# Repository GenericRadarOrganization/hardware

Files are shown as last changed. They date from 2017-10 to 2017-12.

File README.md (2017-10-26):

# hardware
Design Files for Radar Board. Including Kicad Project and Individual Schematics

# Program Requirements
* KiCAD : http://kicad-pcb.org/download/
* GitDesktop (Optional) : https://desktop.github.com/

# How to Operate:
1. Checkout Repositiory
2. Open the "Radar.pro"
3. Find the Schemtatic of which you are responsible for and do your work within that
4. Commit and push your changes, making sure you only changed your schematic
5. Make sure to Pull before you begin edditing

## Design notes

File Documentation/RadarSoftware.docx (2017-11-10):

Software/Signal Processing

This document outlines the basic behavior of the software components of the radar project. The software is responsible for the management of a collection of inputs and outputs: the VCO control waveform, the VCO enable signal, and the mixed-down receive waveform. It uses those inputs and outputs to calculate the range and speed of an object. To accomplish this, the software has been divided into four basic modules: ADC, ADC processing, DAC, and GUI.

The ADC and ADC processing modules are closely interrelated. To ensure a consistent sample rate, the ADC module uses a hardware peripheral of the MKL26Z4 microcontroller on the teensy board called the periodic interrupt timer (PIT) to generate a constant clock signal at the desired sampling frequency. The ADC can then be configured to start a conversion on every rising clock edge of the PIT. This allows consistent conversion with no processor intervention. To close the loop, the direct memory access (DMA) module is configured to automatically transfer data from the ADC to a 512 byte buffer whenever a new reading is available. This allows the firmware to trigger a reading of 512 12-bit words from the ADC at a constant sample rate with only one function call to trigger the required peripherals.

The ADC processing module uses the ADC module’s API to trigger readings and then process the returned data. To determine the frequency of the input waveform, some basic processes are used. First, the module loops over the collected data and determines the average value. Then, the module subtracts that average from every sample. The module then loops over the data to find zero crossings, recording the index of each crossing found. Finally, the difference between each recorded index is averaged together and doubled to calculate the average period (in samples) of the collected waveform. The received frequency can then be determined by dividing the sampling rate by the average period in samples.

The DAC module facilitates control of the transmit stage of the radar. It outputs a constant voltage or a variable voltage waveform to control the output frequency of the VCO. Currently, the DAC is configured to output a set voltage to keep the VCO at a continuous frequency. This is important for use as a doppler radar. The user can configure the voltage output during runtime to change the base frequency of the radar, but sweeps cannot yet be configured. The DAC module is planned to allow the user to select the range and period of the sawtooth wave used to sweep the VCO for FMCW operation.

Finally, the GUI module glues together all the underlying modules and handles all user interaction. It displays a splash screen on an LCD with the company logo upon boot and then switches to the main menu page after a timeout or button press. The user can then use the hardware buttons to enable or disable the radar, vary the frequency of operation, or force the radar to operate in one-shot mode. In one-shot mode, the radar will only capture and process one 512-byte block of data. This would allow the user to point the radar at an object of interest and capture a single speed or distance measurement.

The firmware is maintained on Github: https://github.com/GenericRadarOrganization/firmware. It requires that the user has the arm-none-eabi flavor of GCC installed locally as well as the teensy loader CLI for loading the firmware. To build and flash the firmware, the command “make burn” must be run in the root directory of the project.

ECE 764 Radar Project Thomas Gorham

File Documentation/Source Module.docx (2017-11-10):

Source Module - Damian Loya

The goal of this portion of the Radar is to create and send a clean 5.8 GHz signal to the other modules. This is done by using a voltage controlled oscillator whose output frequency will be set by an Teensy ADC output. The output frequency will be 1.93 GHz which is then multiplied into the desired 5.8 GHz, after being amplified. After the multiplier there is a filter to attenuate any of the 1.93 GHz that leaks through the multiplier. The 5.8 GHz signal is then amplified again before being split in the Wilkinson divider. This module is found on the fourth page of the schematic, based on the initial block diagram given in the project description. I will now explain each of the components in more detail.

Starting off is the voltage controlled oscillator (VCO), the exact model is MAX 2752. This component can take in a voltage from 0V to 3.3V (VCC) which corresponds to its frequency range of 1875 MHz to 2275 MHz. The supporting circuitry is set up according to the application guide found in the datasheet.

The Amplifiers Selected are the GALI -2+ because they were the best performing at 5.8GHz according to the data sheet. The simulated gain of each one had around 12 dB of gain, a more detailed chart which the different power levels is included as well. To power the amplifiers there is a DC line with a AC grounding capacitor at a distance of λ/4 from the output. There are also DC blocking capacitors on both the inputs and outputs.

The frequency multiplier being used is the RMK -3-93+. This is one of the reasons, so much gain is needed from the amplifiers. It needs at least 7dBm of input and has a conversion loss of around 16.5 DB at 5.8GHz. On issues is that it lets through a decent amount of the original frequency. This is an issue because we do not want to unintentionally transmit this frequency. So the output signal is then filtered with a single pole filter to further attenuate the 1.9 GHz signal.

Once Amplified again the signal is sent through a Wilkinson power divider. This ideal should take a signal and split it into two -3dB signals. When simulated in ADS each signal was closer to -3.1dB. Drawing the Shape within KiCad was one factor that lead to a blockier shape rather than a horse shoe or omega shape.

Also included on the Schematic is a resistive divider which could be used to monitor the 1.93 GHz signal form the VCO. Th pads could be left unpopulated and zero-ohm resistors can be used to bypass it. Another thing that was placed on the VCO board was the Voltage regulator which takes in 9V from the battery and regulates it to 5V. The Teensy is powered of this, and also is used to regulate the 5V. into 3.3V.

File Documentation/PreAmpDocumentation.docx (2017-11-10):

Downconverter/Baseband Preamp Module – Katie Dhuyvetter

This portion of the radar converts the high RF signal coming in from the TX/RX module to a low RF signal. It also contains the preamp so that the weak electrical signal can be processed by the DSP module.

The circuit schematic for this module can be seen on page two of the schematic. The initial circuit was based off the simplified block diagram given in the project assignment packet. I began the circuit by looking at the data sheets of the various parts needed. I selected the following parts: LMV751 low-noise op-amps, MCA1-85L+ frequency mixer, GALI-1+ amplifier, resistors, capacitors, and a potentiometer. The resistors and the capacitors were used in conjunction with the amplifiers to get the desired gain. The potentiometer was selected so that the gain of the preamp can be easily altered. The remaining parts will be discussed in more detail below.

The low-noise op-amps were selected to be used as the preamp gain amplifiers. Resistor values were chosen such that the first op amp gives a gain of 1000. The second op-amp uses the potentiometer to have a variable gain value. The DSP module needs 3.3 V of input, so the variable gain amp will allow us to alter the input gain such that it is the correct value.

The GALI-1+ was chosen as the amplifier that connects the source module with the frequency mixer. This is because upon inspection of the data sheet, the frequency mixer was found to need +4 dBm of input and the GALI-1+ was the smallest amplifier provided with a gain of 10 dB. Capacitor values were chosen based on the frequency value of 5.8 GHz to accompany the amplifier. These values were able to be taken from the third lab because the same amp and frequency were used for the lab.

The frequency mixer takes in the local oscillator value from the amplified source module input and the RF input directly from the TX/RX module. The mixer is used to mix the two frequencies, creating a new output frequency. It is the first step of the downconverter system for this module. The next step of the downconverter is the low pass filter. The low pass filter was first created using the LMV751 op amp along with a resistor and a capacitor. The filter was then altered from the op-amp based filter to a single-pole stub filter. The new filter is a simpler way to filter the signal. The stub length was set to a quarter of the wavelength. The calculations used to find the wavelength can be seen below.

v= c/(√(ε_r))

λ= v/f

The εr value used was 4.6 and the frequency used was 5.8 GHz. The final value of the stub length was calculated to be 0.2374 inches.

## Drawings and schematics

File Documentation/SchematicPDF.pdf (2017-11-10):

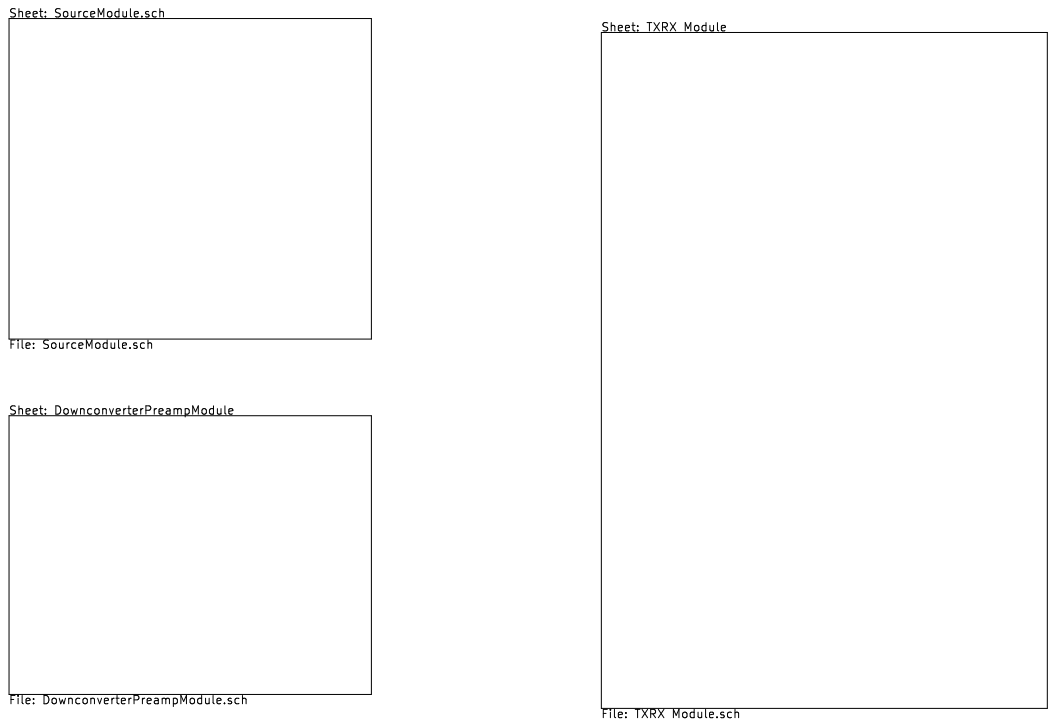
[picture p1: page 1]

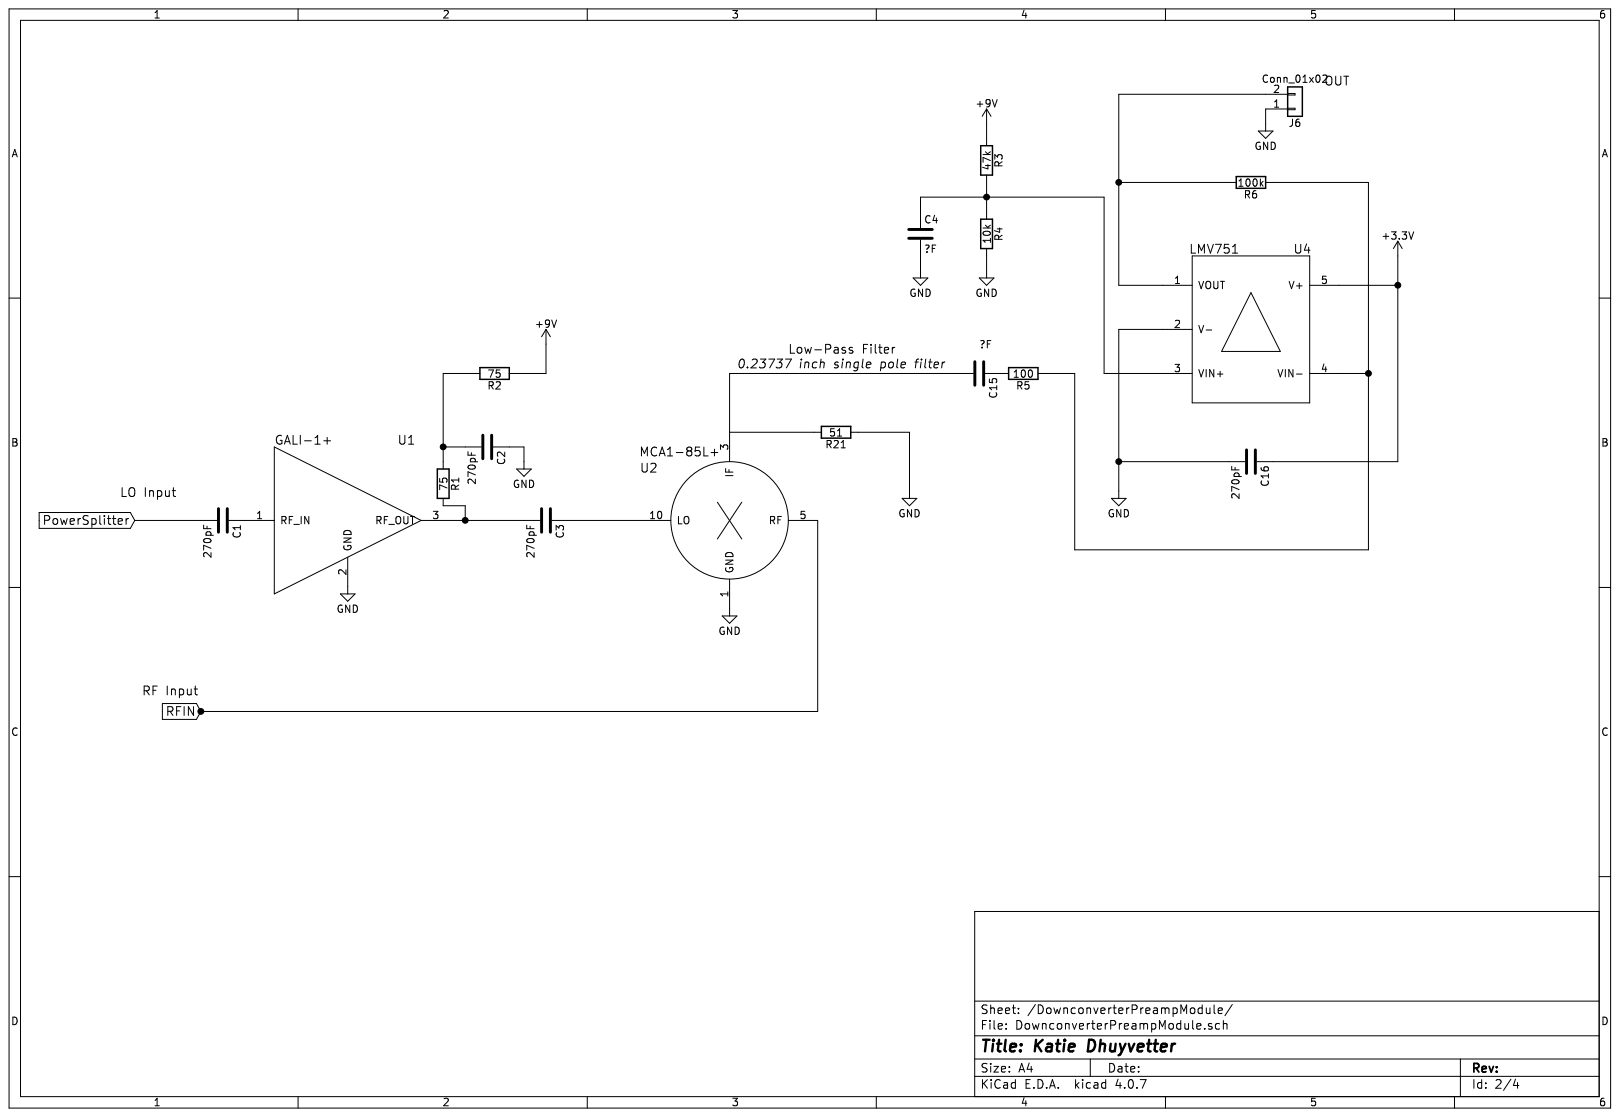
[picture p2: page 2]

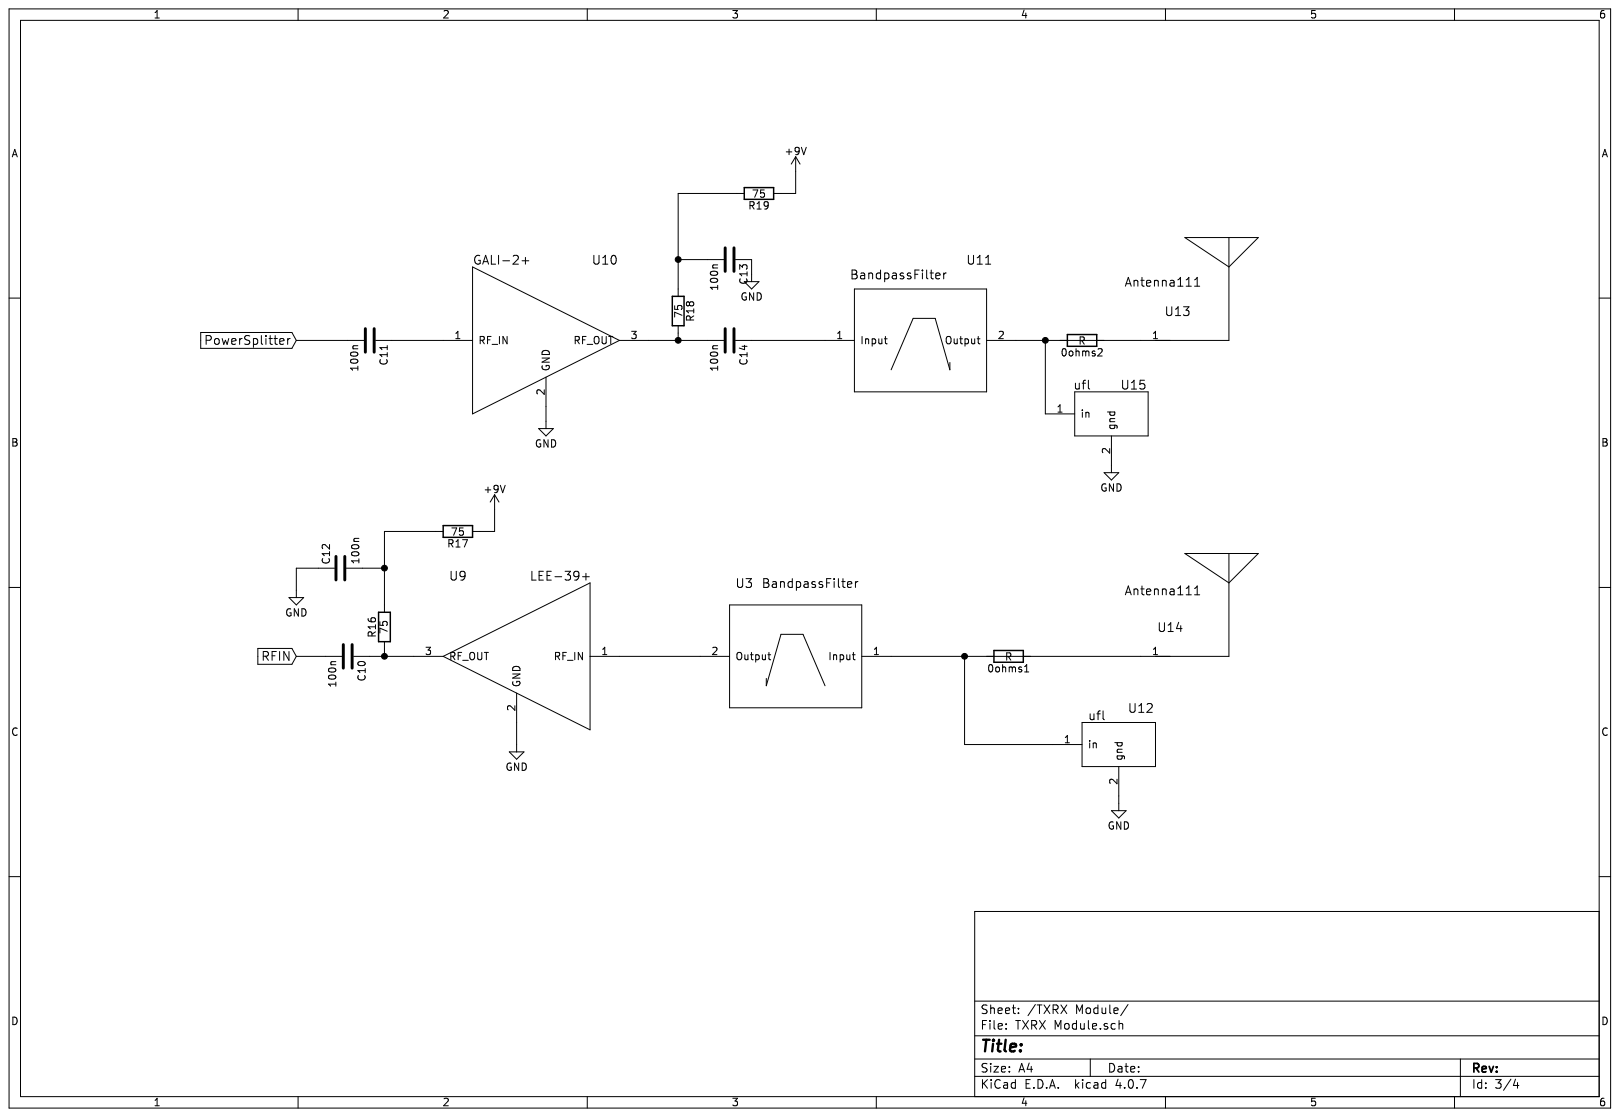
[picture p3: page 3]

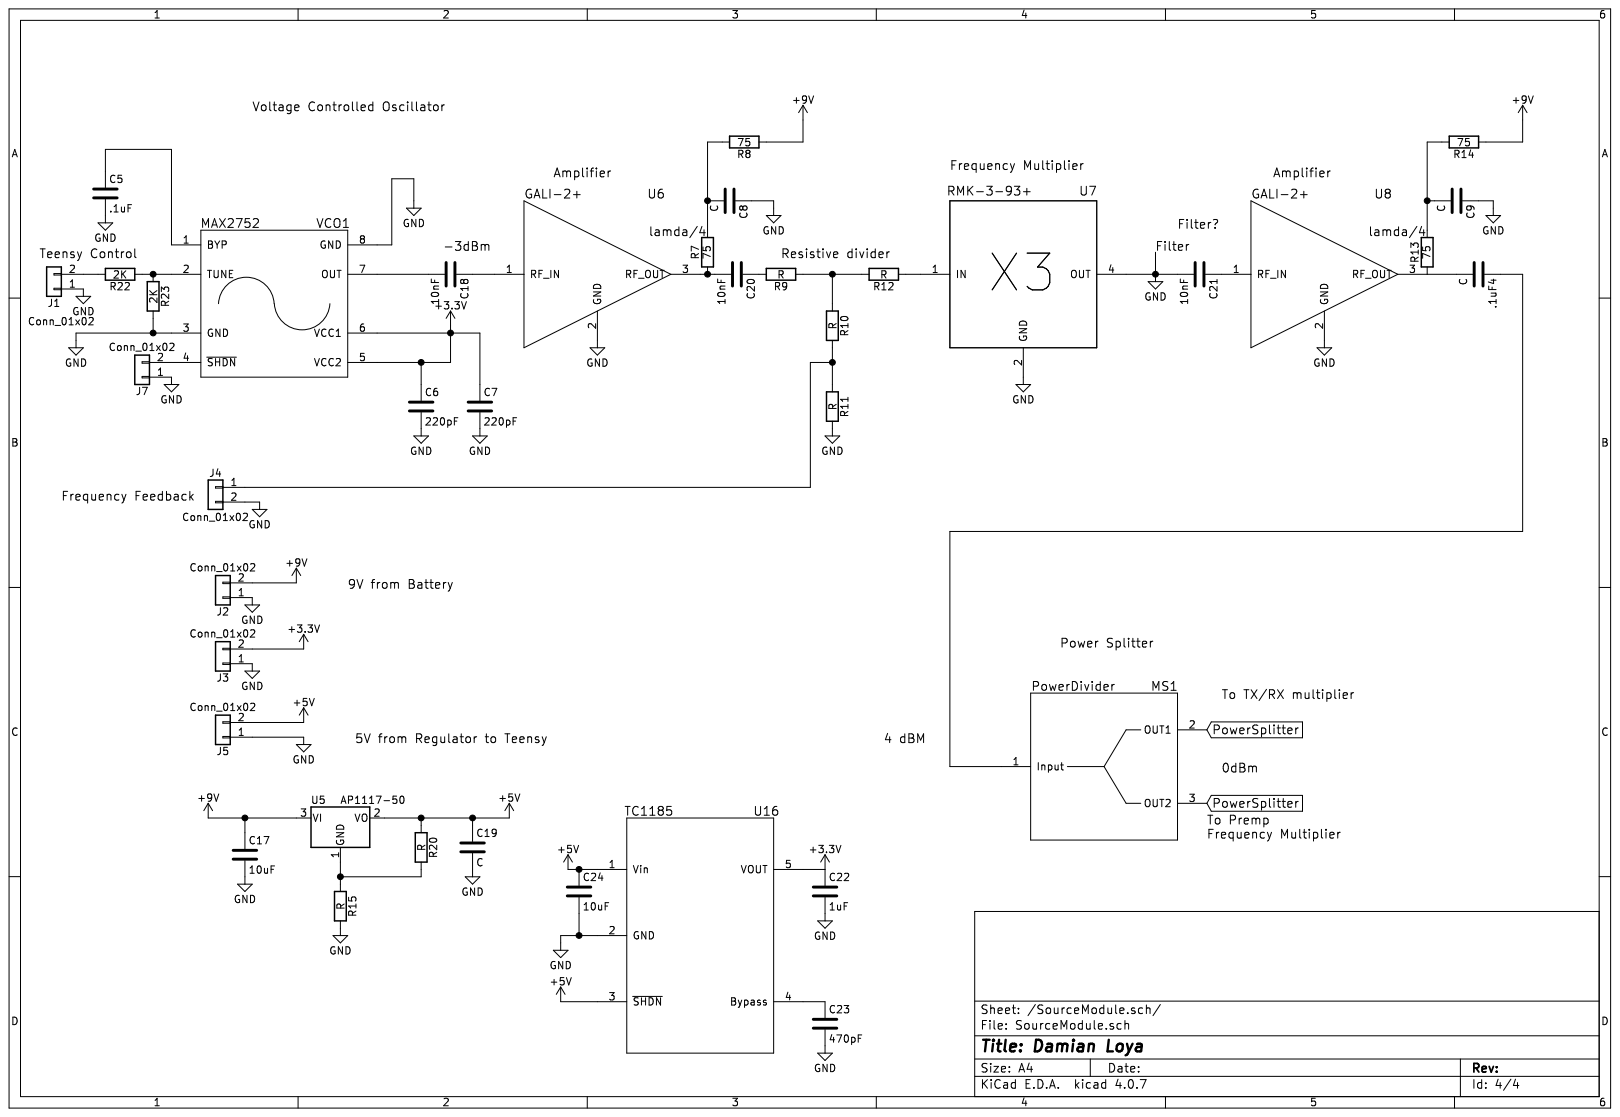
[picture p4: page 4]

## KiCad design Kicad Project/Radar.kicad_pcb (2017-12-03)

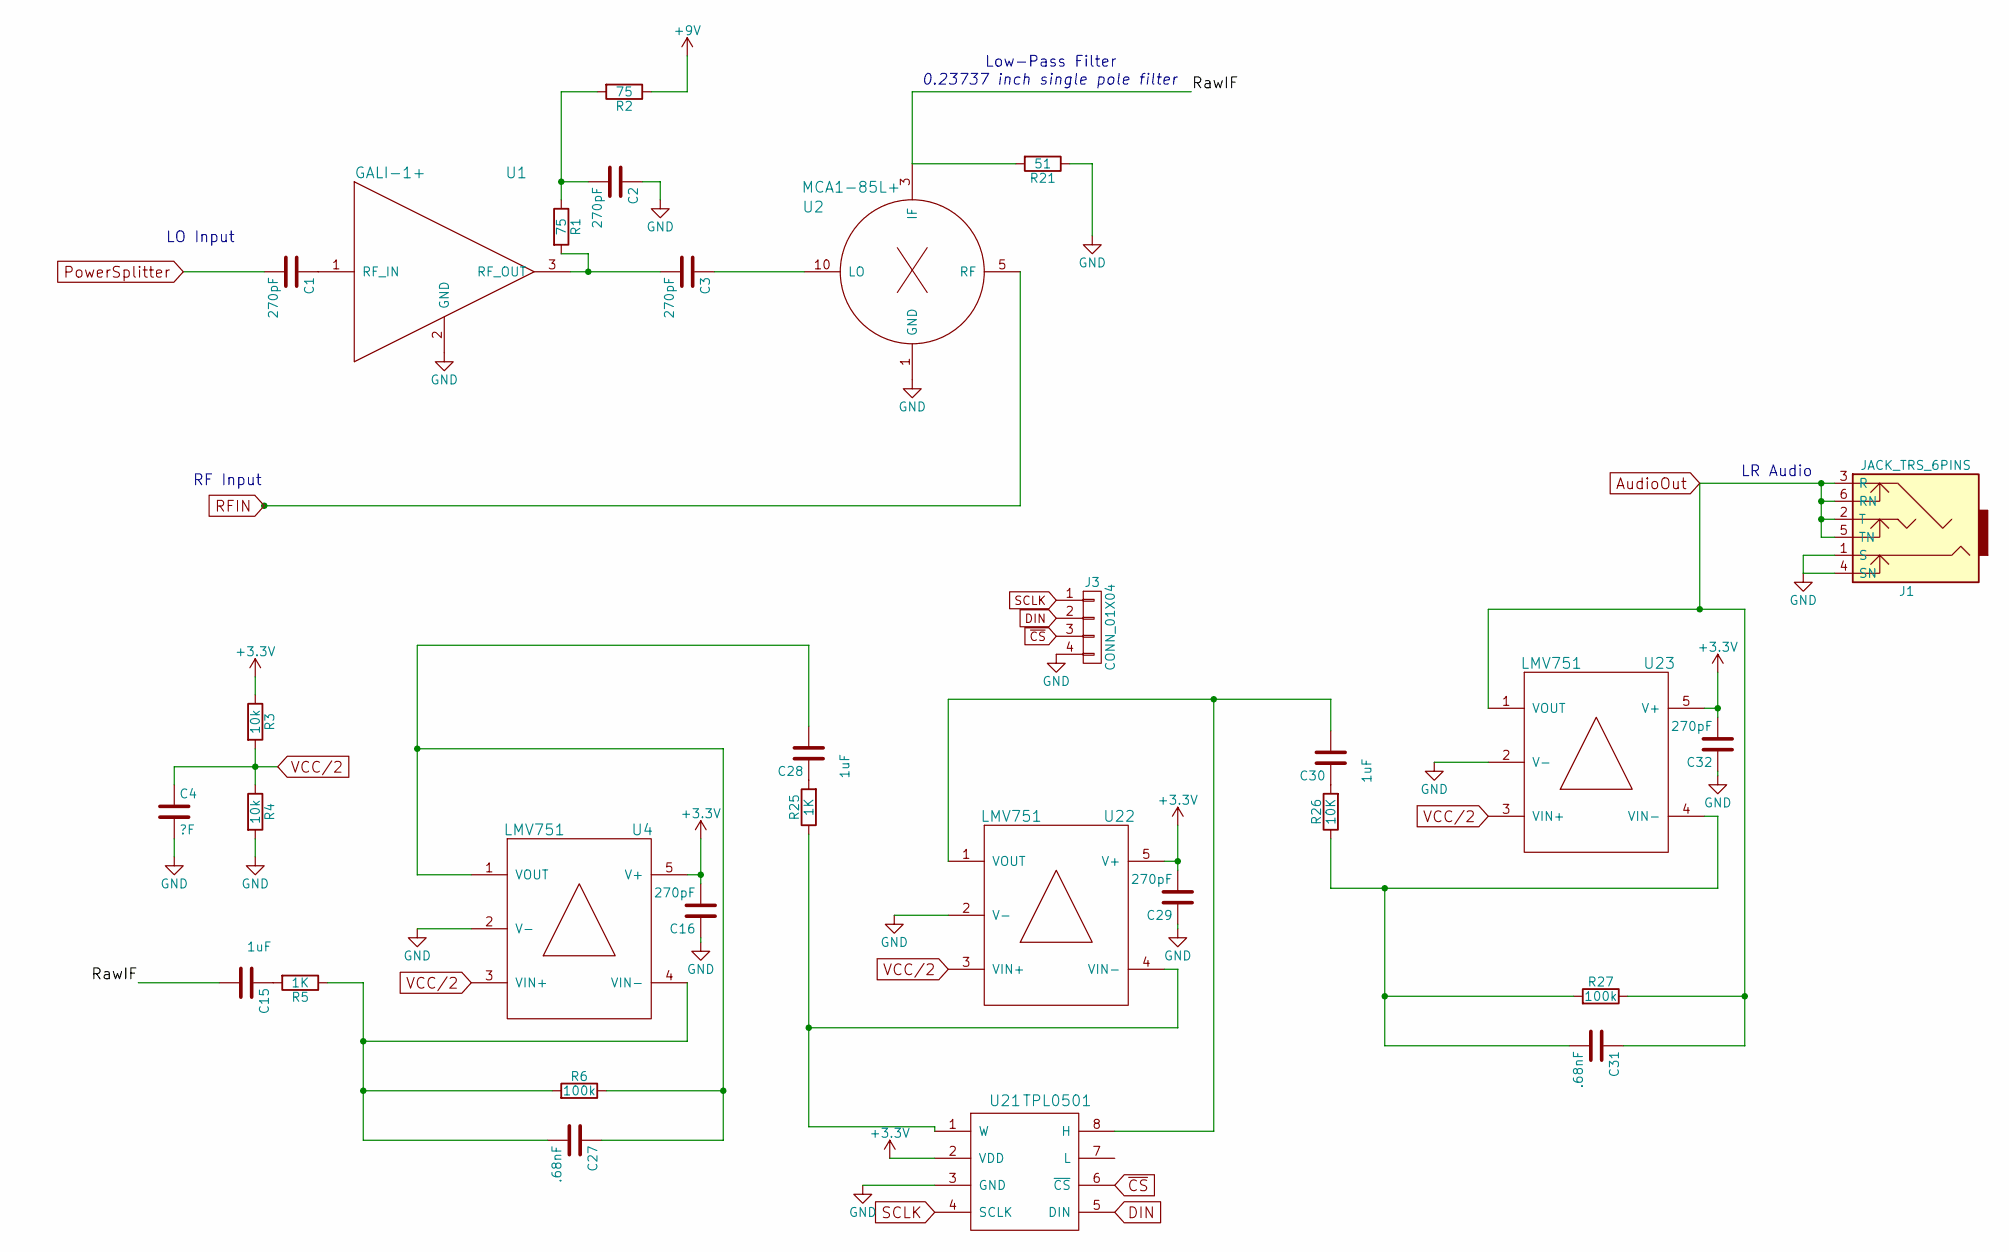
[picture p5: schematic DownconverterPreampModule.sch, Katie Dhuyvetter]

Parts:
C1, C3: 270pF; 100PAD
C2: 270pF; 100PAD+GND3
C4: ?F; C_0603
C15, C28, C30: 1uF; C_0603
C16, C29, C32: 270pF; C_0603
C27, C31: .68nF; C_0603
J1: JACK_TRS_6PINS; 3.5mm_SMD
J3: CONN_01X04; Pin_Header_Straight_1x04_Pitch2.54mm
R1: 75; 100PAD
R2: 75; 100PAD+GND
R3, R4: 10k; R_0603
R5, R25: 1K; R_0603
R6, R27: 100k; R_0603
R21: 51; R_0603
R26: 10K; R_0603
U1: GALI-1+; Amplifier
U2: MCA1-85L+; DZ885
U4, U22, U23: LMV751; SOT23-5
U21: TPL0501; SOT-23(8)

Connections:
+3V3: C16.2, C29.2, C32.2, R3.1, U4.5 (V+), U21.2 (VDD), U22.5 (V+), U23.5 (V+); also elsewhere on the board
+9V: R2.1; also elsewhere on the board
/DownconverterPreampModule/RawIF: C15.2, R21.2, U2.3 (IF)
AudioOut: C31.1, J1.2 (T), J1.3 (R), J1.5 (TN), J1.6 (RN), R27.1, U23.1 (VOUT); also elsewhere on the board
DIN: J3.2, U21.5 (DIN)
GND: C2.1, C4.2, C16.1, C29.1, C32.1, J1.1 (S), J1.4 (SN), J3.4, R4.2, R21.1, U1.2 (GND), U2.1 (GND), U2.2, U2.4, U2.6, U2.7, U2.8, U2.9, U4.2 (V-), U21.3 (GND), U22.2 (V-), U23.2 (V-); also elsewhere on the board
unnamed: C1.1, U1.1 (RF_IN)
unnamed: C2.2, R1.1, R2.2
unnamed: C3.1, U2.10 (LO)
unnamed: C3.2, R1.2, U1.3 (RF_OUT)
unnamed: C15.1, R5.2
unnamed: C27.1, C28.2, R6.1, U4.1 (VOUT)
unnamed: C27.2, R5.1, R6.2, U4.4 (VIN-)
unnamed: C28.1, R25.2
unnamed: C30.1, R26.2
unnamed: C30.2, U21.8 (H), U22.1 (VOUT)
unnamed: C31.2, R26.1, R27.2, U23.4 (VIN-)
unnamed: R25.1, U21.1 (W), U22.4 (VIN-)
PowerSplitter: C1.2; also elsewhere on the board
RFIN: U2.5 (RF); also elsewhere on the board
SCLK: J3.1, U21.4 (SCLK)
VCC/2: C4.1, R3.2, R4.1, U4.3 (VIN+), U22.3 (VIN+), U23.3 (VIN+)
~CS: J3.3, U21.6 (~CS)

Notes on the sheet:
LO Input
RF Input
Low-Pass Filter
0.23737 inch single pole filter
LR Audio

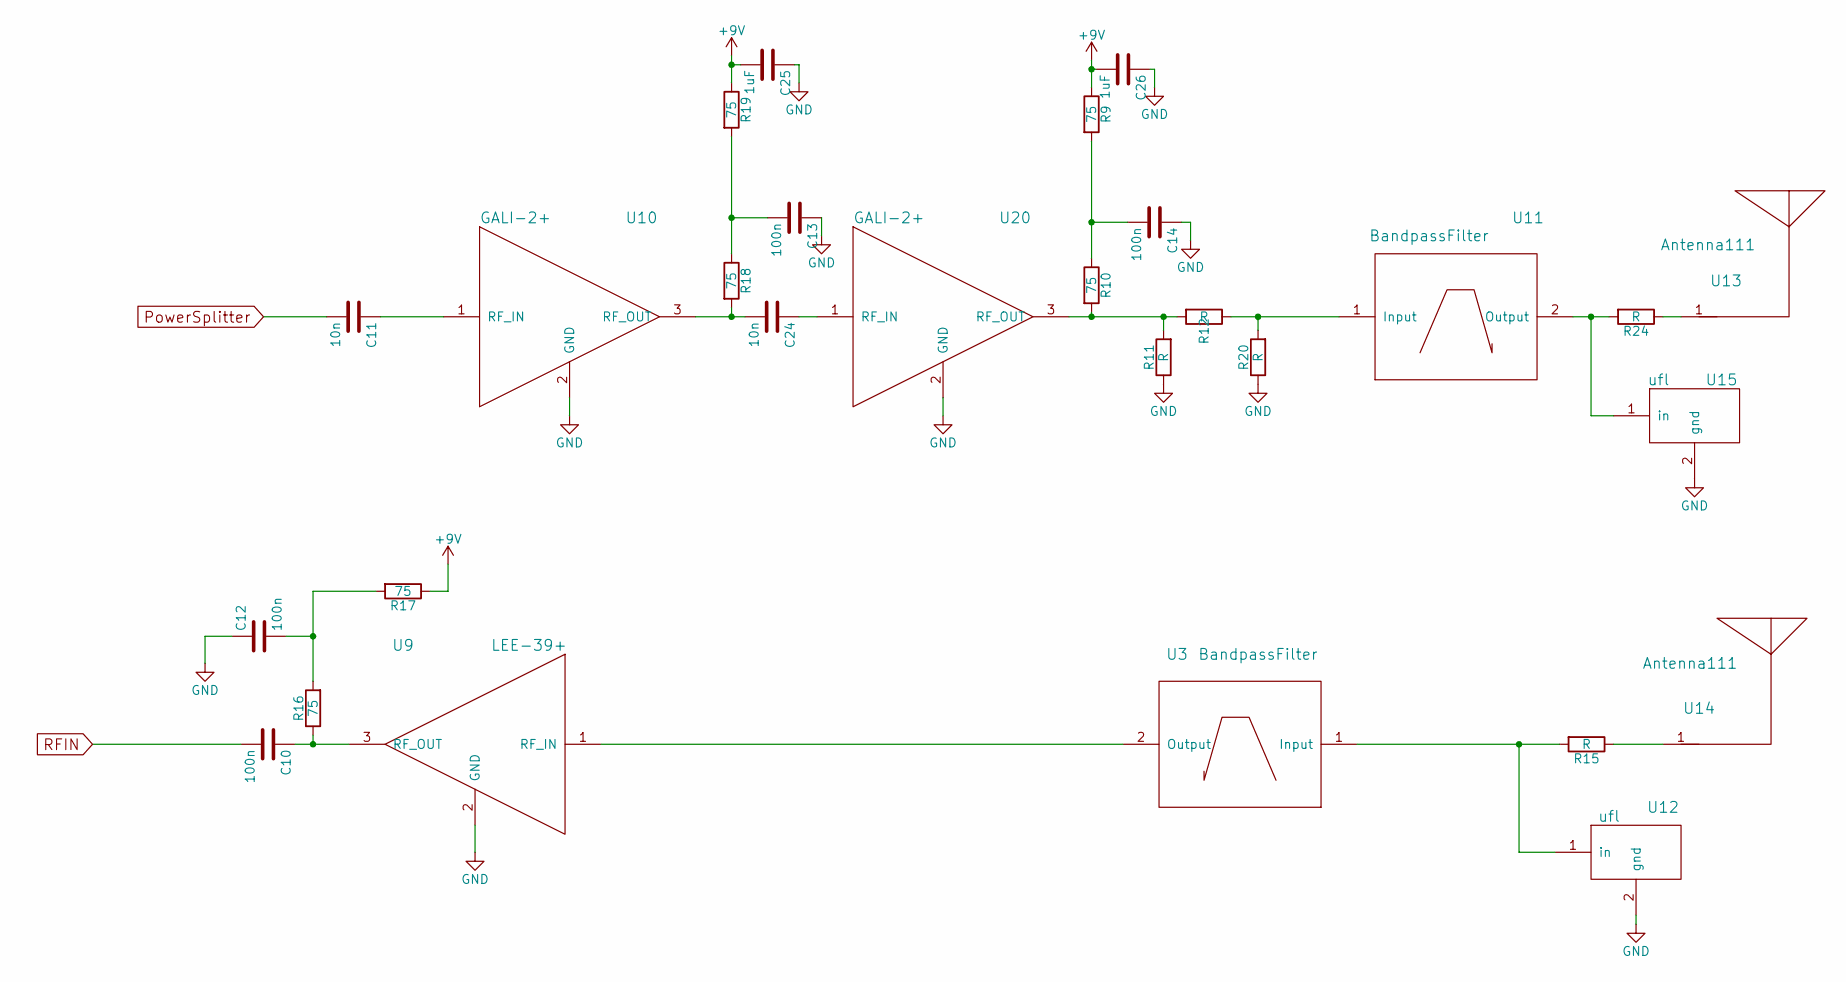
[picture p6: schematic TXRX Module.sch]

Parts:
C10: 100n; 100PAD
C11, C24: 10n; 100PAD
C12, C13, C14: 100n; 100PAD+GND3
C25, C26: 1uF; C_0603
R9, R19: 75; 100PAD+GND2
R10, R16, R18: 75; 100PAD
R11, R20: R; 100PAD+GND2
R12, R15, R24: R; 100PAD
R17: 75; 100PAD+GND
U3: BandpassFilter; QuadPoleFilterMirror
U9: LEE-39+; Amplifier
U10, U20: GALI-2+; Amplifier
U11: BandpassFilter; QuadPoleFilter
U12, U15: ufl; UFL
U13, U14: Antenna111; patch58

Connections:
+9V: C25.2, C26.2, R9.1, R17.1, R19.1; also elsewhere on the board
GND: C12.1, C13.1, C14.1, C25.1, C26.1, R11.1, R20.1, U9.2 (GND), U10.2 (GND), U12.2 (gnd), U15.2 (gnd), U20.2 (GND); also elsewhere on the board
unnamed: C10.1, R16.1, U9.3 (RF_OUT)
unnamed: C11.1, U10.1 (RF_IN)
unnamed: C12.2, R16.2, R17.2
unnamed: C13.2, R18.1, R19.2
unnamed: C14.2, R9.2, R10.1
unnamed: C24.1, U20.1 (RF_IN)
unnamed: C24.2, R18.2, U10.3 (RF_OUT)
unnamed: R10.2, R11.2, R12.2, U20.3 (RF_OUT)
unnamed: R12.1, R20.2, U11.1 (Input)
unnamed: R15.1, U14.1
unnamed: R15.2, U3.1 (Input), U12.1 (in)
unnamed: R24.1, U13.1
unnamed: R24.2, U11.2 (Output), U15.1 (in)
unnamed: U3.2 (Output), U9.1 (RF_IN)
PowerSplitter: C11.2; also elsewhere on the board
RFIN: C10.2; also elsewhere on the board

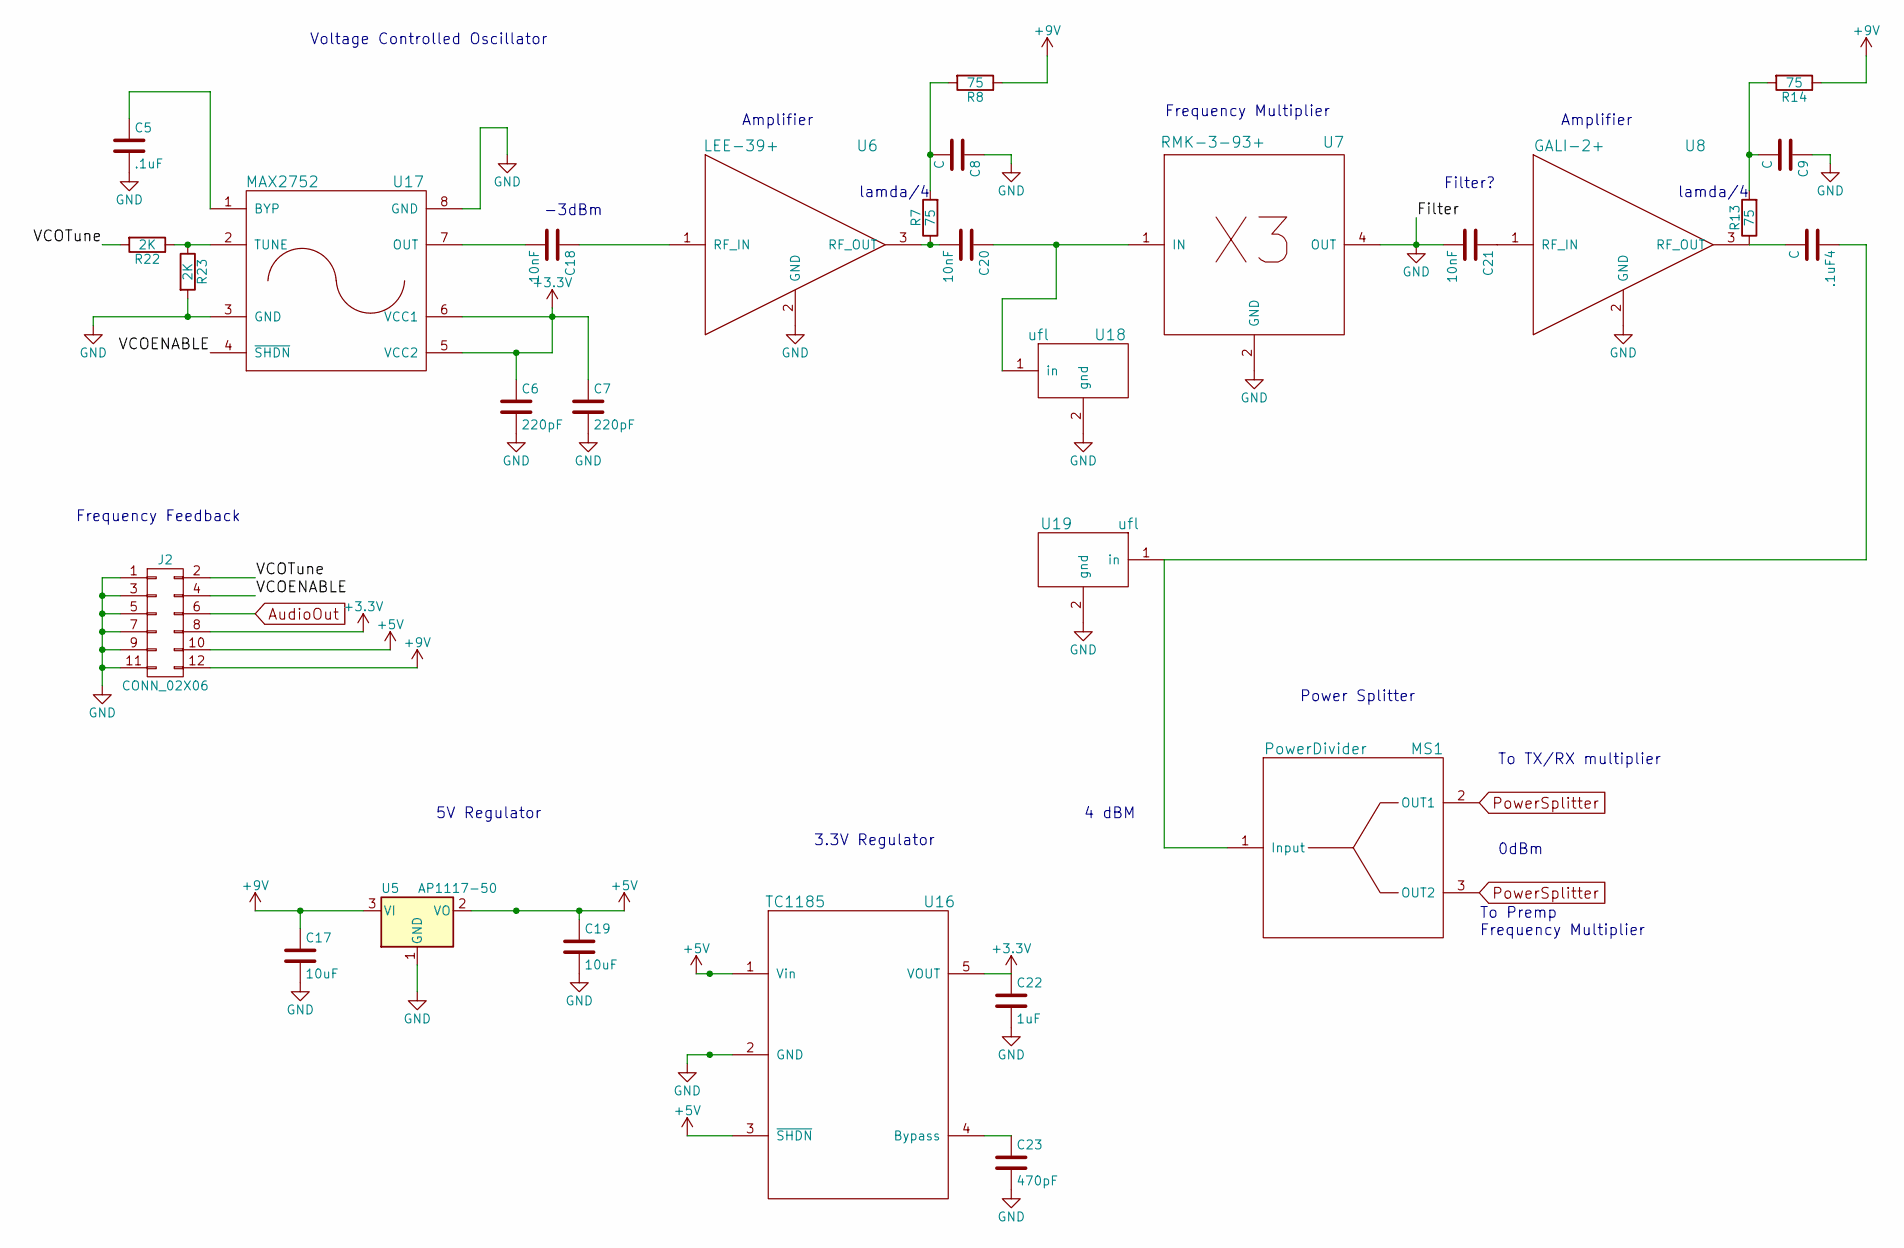
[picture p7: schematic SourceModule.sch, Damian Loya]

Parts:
.1uF4: C; 100PAD
C5: .1uF; C_0603
C6, C7: 220pF; C_0603
C8, C9: C; 100PAD+GND3
C17: 10uF; C_0805
C18, C20, C21: 10nF; 100PAD
C19: 10uF; C_1210_HandSoldering
C22: 1uF; C_1210_HandSoldering
C23: 470pF; C_0805
J2: CONN_02X06; Pin_Header_Straight_2x06_Pitch2.54mm
MS1: PowerDivider; powersplitter2
R7, R13: 75; 100PAD
R8, R14: 75; 100PAD+GND
R22, R23: 2K; R_0603
U5: AP1117-50; ZLDO1117
U6: LEE-39+; Amplifier
U7: RMK-3-93+; TT1224
U8: GALI-2+; Amplifier
U16: TC1185; SOT23-5
U17: MAX2752
U18, U19: ufl; UFL

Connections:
+3V3: C6.1, C7.1, C22.1, J2.8, U16.5 (VOUT), U17.5 (VCC2), U17.6 (VCC1); also elsewhere on the board
+5V: C19.1, J2.10, U5.2 (VO), U16.1 (Vin), U16.3 (~SHDN)
+9V: C17.1, J2.12, R8.1, R14.1, U5.3 (VI); also elsewhere on the board
/SourceModule.sch/VCOENABLE: J2.4, U17.4 (~SHDN)
/SourceModule.sch/VCOTune: J2.2, R22.2
AudioOut: J2.6; also elsewhere on the board
GND: C5.2, C6.2, C7.2, C8.1, C9.1, C17.2, C19.2, C21.2, C22.2, C23.2, J2.1, J2.3, J2.5, J2.7, J2.9, J2.11, R23.2, U5.1 (GND), U6.2 (GND), U7.2 (GND), U7.3, U7.4 (OUT), U7.5, U7.6, U8.2 (GND), U16.2 (GND), U17.3 (GND), U17.8 (GND), U18.2 (gnd), U19.2 (gnd); also elsewhere on the board
unnamed: .1uF4.1, MS1.1 (Input), U19.1 (in)
unnamed: .1uF4.2, R13.1, U8.3 (RF_OUT)
unnamed: C5.1, U17.1 (BYP)
unnamed: C8.2, R7.2, R8.2
unnamed: C9.2, R13.2, R14.2
unnamed: C18.1, U6.1 (RF_IN)
unnamed: C18.2, U17.7 (OUT)
unnamed: C20.1, U7.1 (IN), U18.1 (in)
unnamed: C20.2, R7.1, U6.3 (RF_OUT)
unnamed: C21.1, U8.1 (RF_IN)
unnamed: C23.1, U16.4 (Bypass)
unnamed: R22.1, R23.1, U17.2 (TUNE)
PowerSplitter: MS1.2 (OUT1), MS1.3 (OUT2); also elsewhere on the board

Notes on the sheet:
Voltage Controlled Oscillator
Amplifier
Frequency Multiplier
Power Splitter
To Premp Frequency Multiplier
To TX/RX multiplier
Frequency Feedback
0dBm
-3dBm
lamda/4
4 dBM
Filter?
5V Regulator
3.3V Regulator

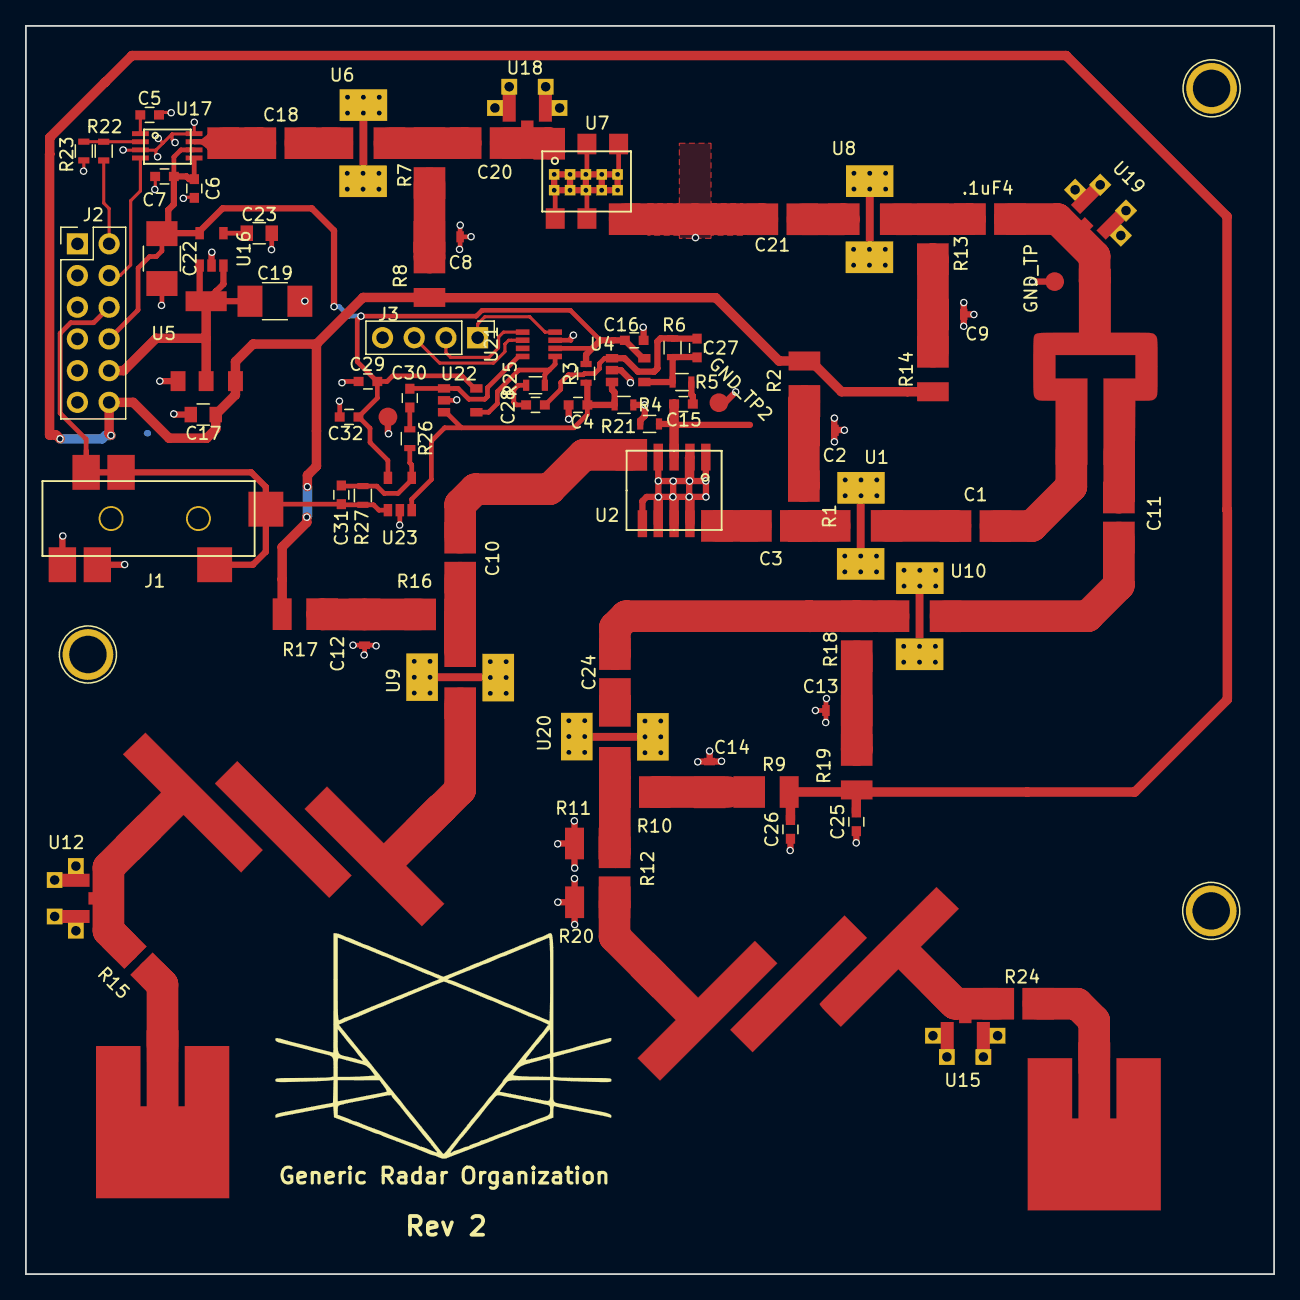
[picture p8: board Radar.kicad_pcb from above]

Board: 2 copper layers, 100.0 x 100.0 mm, 89 parts (0 on the bottom side), 52 nets.

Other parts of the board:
GND_TP, GND_TP2: Measurement_Point_Round-SMD-Pad_Small

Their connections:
GND: GND_TP.1, GND_TP2.1; also elsewhere on the board

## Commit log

2017-10-25 Set up a hierarchy for the Source Module, Tx/RX Module, and DownConverter/Preamp Module
    [DownconverterPreampModule.sch, Radar.kicad_pcb, Radar.sch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]
2017-10-26 Damian edits
    [SourceModule.sch, TXRX Module.sch]
2017-10-26 Added Relative Path to footprint library
2017-10-28 Initial circuit setup
    [DownconverterPreampModule.sch]
2017-10-28 Component Library linked Circuit work on Source Module
    [Radar.sch, SourceModule.sch, TXRX Module.sch]
2017-10-30 Added Power calculations and resistive divider
    [SourceModule.sch]
2017-10-31 Change test
    [DownconverterPreampModule.sch]
2017-10-31 Updated labels
    [SourceModule.sch]
2017-10-31 test of git desktop and kicad
    [TXRX Module.sch]
2017-10-31 Added Hierarchical labels to TX/RX module
    [Radar.sch]
2017-10-31 Added ADS Workspaces
    [dds.cfg, de_sim.cfg, hpeesofsim.cfg]
2017-11-01 Added second amplifier.
    [DownconverterPreampModule.sch]
2017-11-01 Messed with parts
    [SourceModule.sch]
2017-11-05 Updated TxRx module schematic
    [TXRX Module.sch, dds.cfg]
2017-11-06 PCB 1
    [DownconverterPreampModule.sch, Radar.kicad_pcb]
2017-11-06 added antennas and receive end
    [TXRX Module.sch]
2017-11-06 Connected stuffs and things
    [TXRX Module.sch]
2017-11-06 PCB Changes
    [DownconverterPreampModule.sch, Radar.kicad_pcb, SourceModule.sch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]
2017-11-06 Filter edit.
    [DownconverterPreampModule.sch, Radar.sch, SourceModule.sch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]
2017-11-07 PCB and Schematic updates
    [DownconverterPreampModule.sch, Radar.kicad_pcb, SourceModule.sch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]
2017-11-07 fixed merge error
    [DownconverterPreampModule.sch]
2017-11-07 Added capacitor values and power rails
    [Radar.sch, SourceModule.sch, TXRX Module.sch]
2017-11-07 PCB for source Module mostly complete, missing filter. Power Spliter still has issues.
    Some minor changes made to all schematics for the net lists to be properall connected
    A bunch of parts made
    [DownconverterPreampModule.sch, Radar.kicad_pcb, Radar.sch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]
2017-11-07 PCB LAYOUT update
    [DownconverterPreampModule.sch, Radar.kicad_pcb, Radar.sch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]
2017-11-08 pcb stuff
    [Radar.kicad_pcb]
2017-11-08 Added Filters to PCB
    [Radar.kicad_pcb, SourceModule.sch, TXRX Module.sch]
2017-11-08 added zero ohm resistors
    [DownconverterPreampModule.sch, Radar.sch, SourceModule.sch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]
2017-11-08 Added ufl connector to schematic
    [TXRX Module.sch]
2017-11-08 added antennas to pcb
    [Radar.kicad_pcb, TXRX Module.sch]
2017-11-08 Connected patch antennas, removed cap on rx side, added radial stub
    [DownconverterPreampModule.sch, Radar.kicad_pcb, SourceModule.sch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]
2017-11-09 Added Documentation, Fixed Some Footprints
    [GainChart.xlsx, TXRX Module.sch]
2017-11-10 More PCB Updates
    [DownconverterPreampModule.sch, Radar.kicad_pcb, SourceModule.sch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]
2017-11-10 PCB Pre Flood
    [Radar.kicad_pcb, SourceModule.sch, TXRX Module.sch]
2017-11-10 Added GND Flood
    [Radar.kicad_pcb]
2017-11-10 PCB Updates and added some Project outputs, like gerbers and schematic pdf
    [Radar.kicad_pcb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]
2017-11-10 Changed Routing of 9V line, added more documentation
    [GainChart.xlsx, Radar.kicad_pcb]
2017-11-10 Gain Chart updated
    [GainChart.xlsx]
2017-11-10 grammar and spelling
    [GainChart.xlsx]
2017-11-10 Changed caps on tx rx to 100n
    [TXRX Module.sch]
2017-11-10 PCB Edits post PDR
    [DownconverterPreampModule.sch, Radar.kicad_pcb, SourceModule.sch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]
2017-11-10 updated gerbers
    [Radar.kicad_pcb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]
2017-11-10 Rev 1!
    Gerbers Generated
    Sent to Smart
    [DownconverterPreampModule.sch, Radar.kicad_pcb, SourceModule.sch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]
2017-11-10 Gerbers updated with correct file extensions
    [Radar-B.Cu.gbl, Radar-B.Mask.gbs, Radar-B.Paste.gbp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]
2017-11-28 Rev 2 update 1
    Changes for Rev2:
    Mounting Holes (duh)
    Right Headers
    HeadphoneJack
    Added tantulum Caps at Regulators
    Added UFL conns
    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
    [DownconverterPreampModule.sch, Radar.kicad_pcb, SourceModule.sch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]
2017-11-28 More Routing
    [DownconverterPreampModule.sch, Radar.kicad_pcb, SourceModule.sch]
2017-12-01 Updated tx/rx schematic for two amps on chains
    [TXRX Module.sch]
2017-12-01 Damian's almost to rev 2 completion, needs audio amps
    [DownconverterPreampModule.sch, Radar.kicad_pcb, SourceModule.sch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]
2017-12-02 Fixed Merge Stuff With TX/RX board
    [TXRX Module.sch]
2017-12-02 Added some Gain calcs for the RX side
    [Power Calcs.xlsx]
2017-12-03 Rev 2?
    [DownconverterPreampModule.sch, Power Calcs.xlsx, Radar.kicad_pcb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]
2017-12-03 New Gerbers, Shipped
    [DownconverterPreampModule.sch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]
